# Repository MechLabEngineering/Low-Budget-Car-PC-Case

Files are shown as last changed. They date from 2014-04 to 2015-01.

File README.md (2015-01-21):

Low-Budget-Car-PC-Case
======================

Case for Tinkerforge IMU, GPS and MHS TinyCAN I-XL

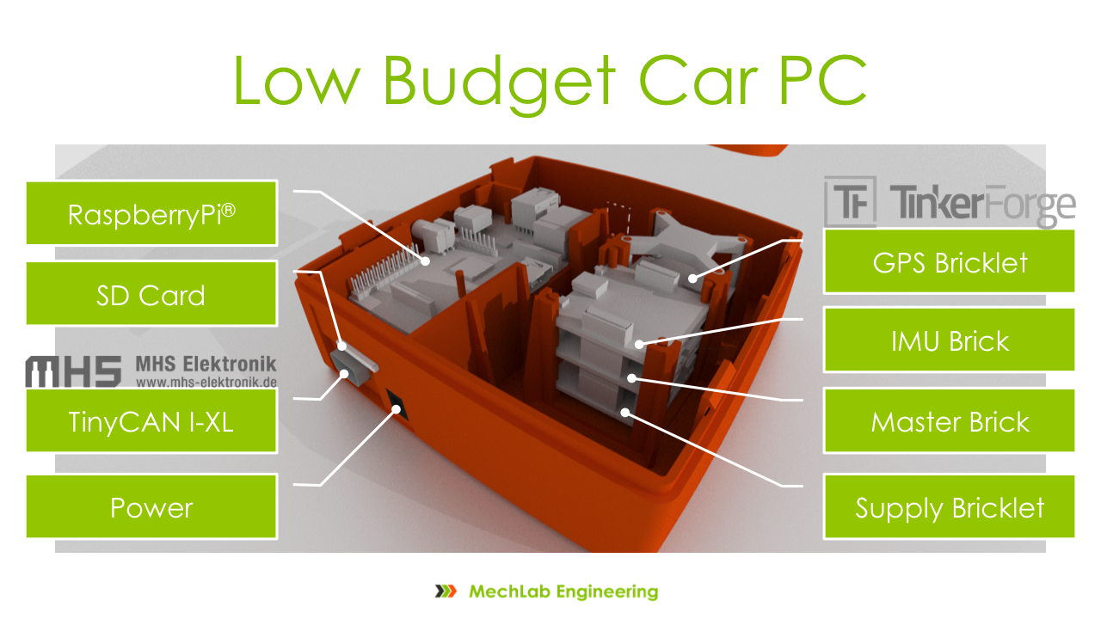
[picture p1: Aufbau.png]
Case


####http://mechlab-engineering.de/references/low-budget-car-pc/
####http://vimeo.com/mechlabengineering/lowbudgetcarpc

## Case for

* [RaspberryPi](http://www.watterott.com/de/Raspberry-Pi-Model-B)
* [Tinkerforge IMU Brick](http://www.tinkerforge.com/de/doc/Hardware/Bricks/IMU_Brick.html)
* [Tinkerforge GPS Bricklet](http://www.tinkerforge.com/en/doc/Hardware/Bricklets/GPS.html)
* [Tinkerforge Power Supply](http://www.tinkerforge.com/de/doc/Hardware/Power_Supplies/Step_Down.html)
* [MHS Elektronik TinyCAN I-XL](http://www.mhs-elektronik.de/index.php?module=content&action=show&page=tinycan_hardware)

With plugable

* USB UMTS Stick
* Ethernet Cable

## Status

We are currently in `Beta` state, that means we 3D printed it already and at least the hardware fits the case. We are tryin' to optimize the cables and the structure for cheaper 3D printing.

[Take a look here](http://mechlab-engineering.de/2014/04/erste-lieferung-car-pc-cases-eingeflogen/)

## Licence

[CC-BY-SA2.0](http://creativecommons.org/licenses/by-sa/2.0/de/) Raphael Borkert

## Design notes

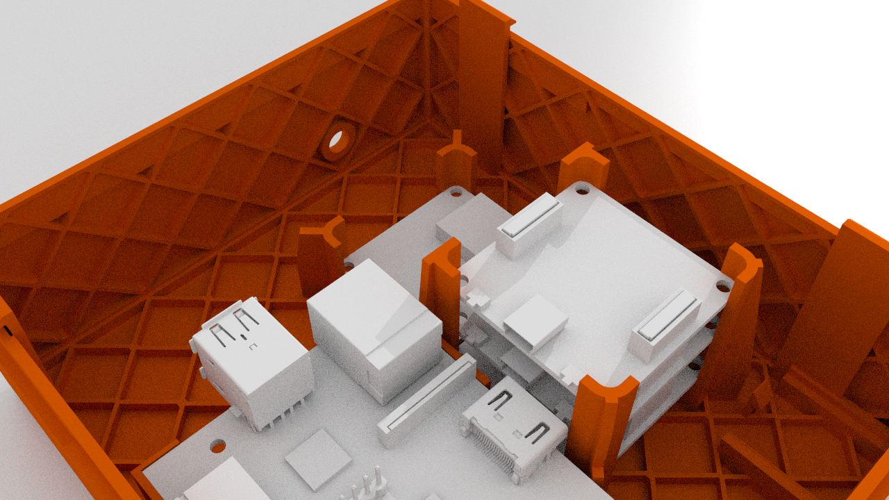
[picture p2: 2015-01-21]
Renderings/RenderingV3.png

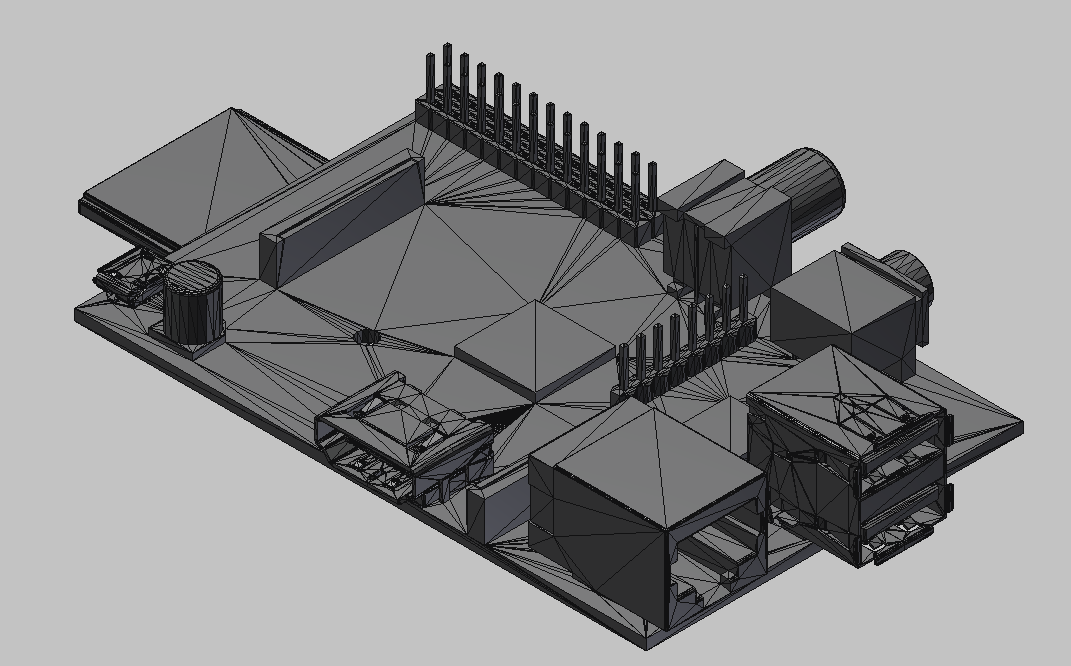
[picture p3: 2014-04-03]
STL-Dateien/RPi_STL_Low.PNG

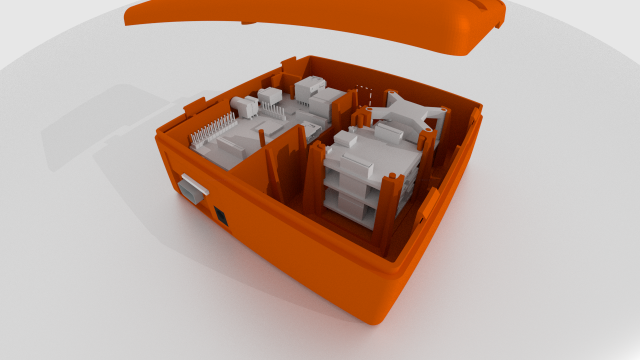
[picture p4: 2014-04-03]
Renderings/Rendering002.png

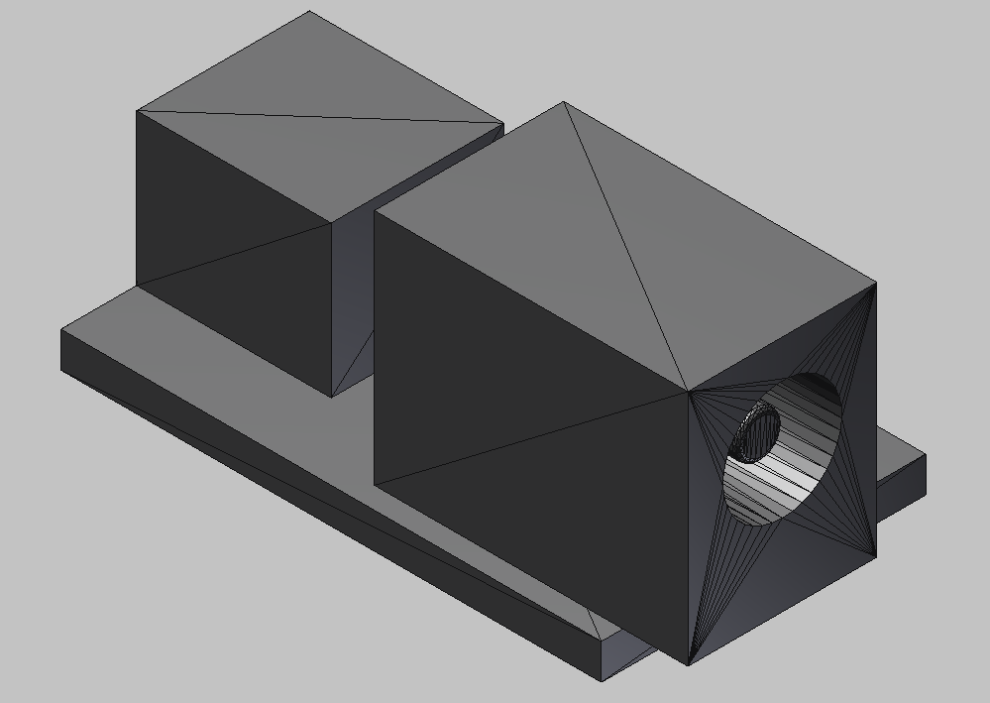
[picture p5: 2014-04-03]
STL-Dateien/DC_Jack_STL_Low.PNG

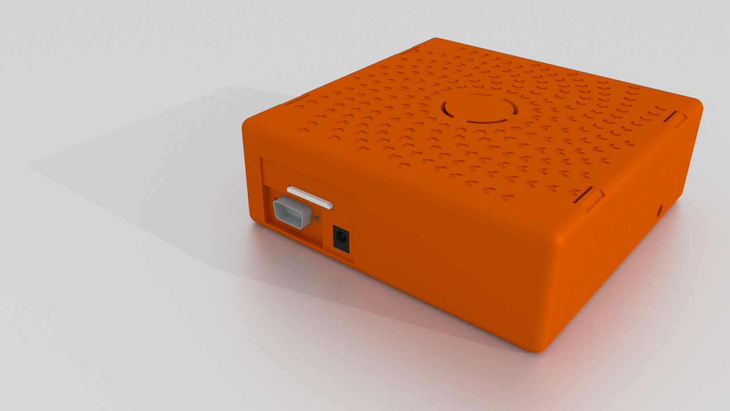
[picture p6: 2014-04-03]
Renderings/Rendering001.png

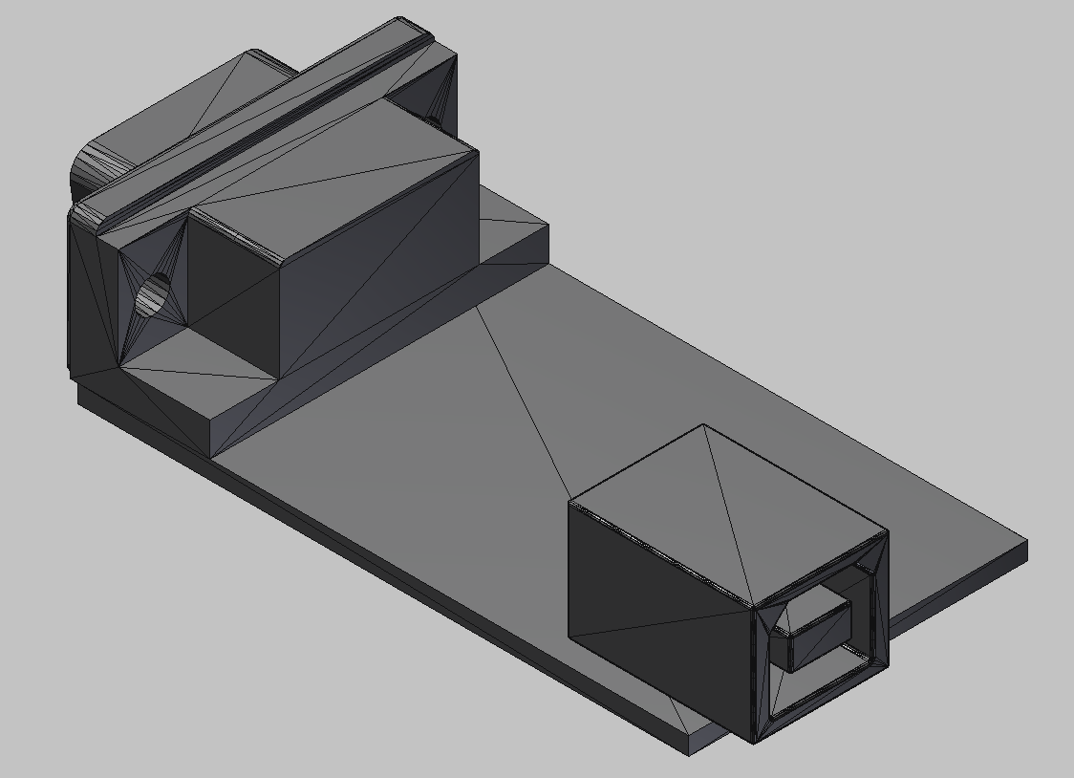
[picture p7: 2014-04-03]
STL-Dateien/Tiny_CAN_STL_Low.PNG

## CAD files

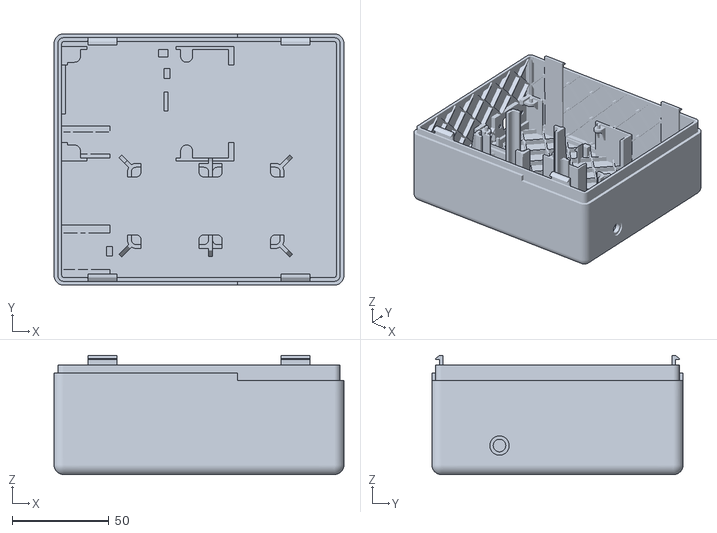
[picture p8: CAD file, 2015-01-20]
STL-Dateien/CarPC_Case_USV.stl
150.0 x 130.0 x 61.6

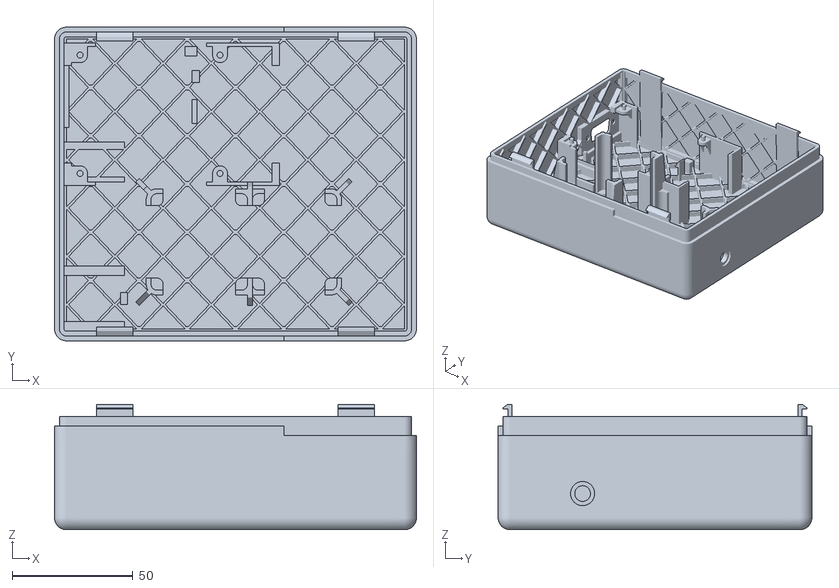
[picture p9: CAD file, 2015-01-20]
STL-Dateien/CarPC_Case.stl
150.0 x 130.0 x 52.0

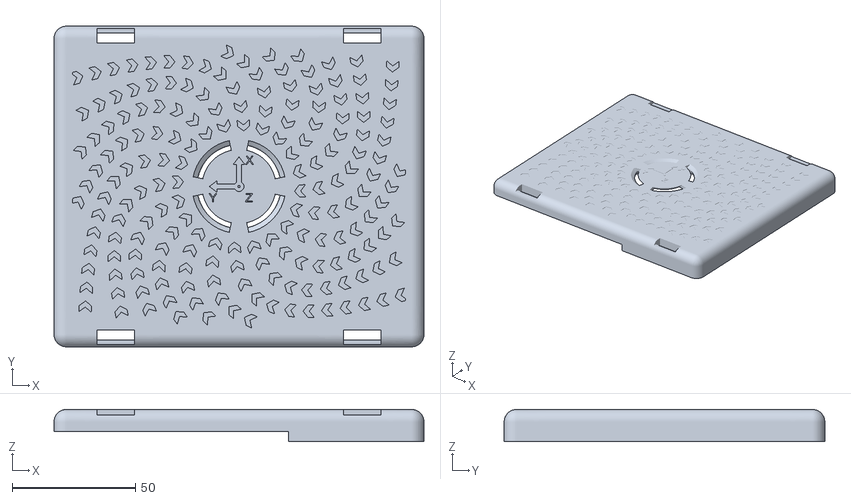
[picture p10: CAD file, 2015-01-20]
STL-Dateien/CarPC_Deckel.stl
150.0 x 130.0 x 13.0

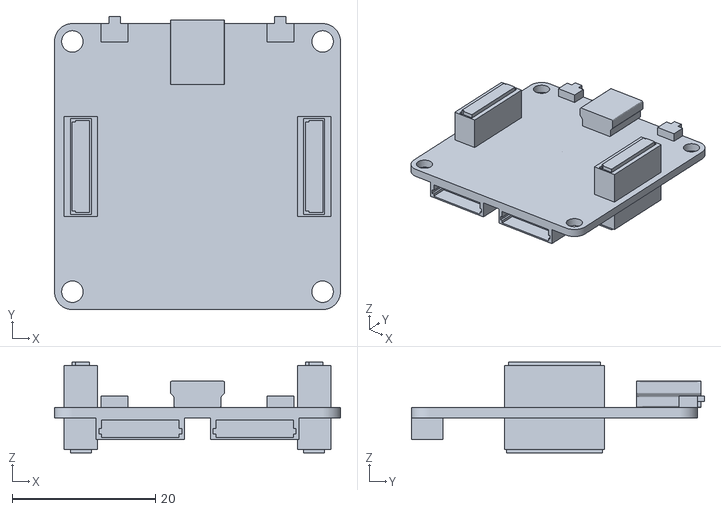
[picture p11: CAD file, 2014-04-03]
STL-Dateien/IMU.stl
40.0 x 41.0 x 12.7

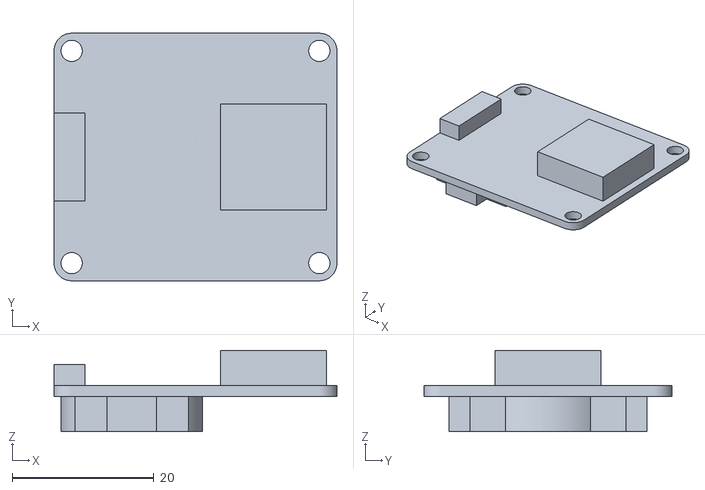
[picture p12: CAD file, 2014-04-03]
STL-Dateien/GPS_Bricklet.stl
40.0 x 35.0 x 11.5

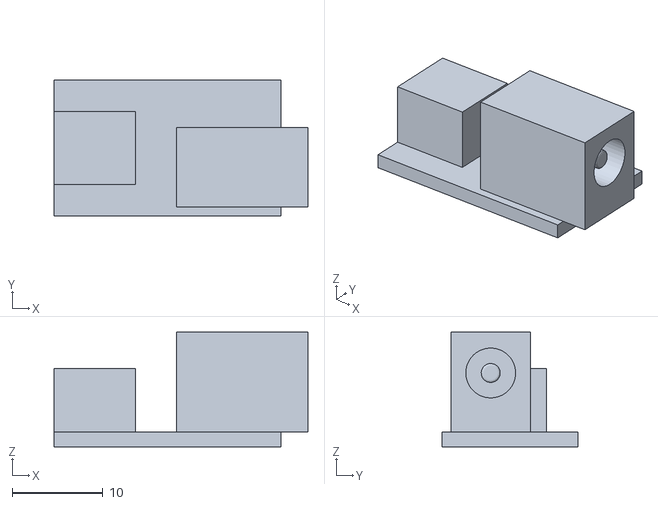
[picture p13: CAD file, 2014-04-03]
STL-Dateien/DC_Jack.stl
28.0 x 15.0 x 12.6

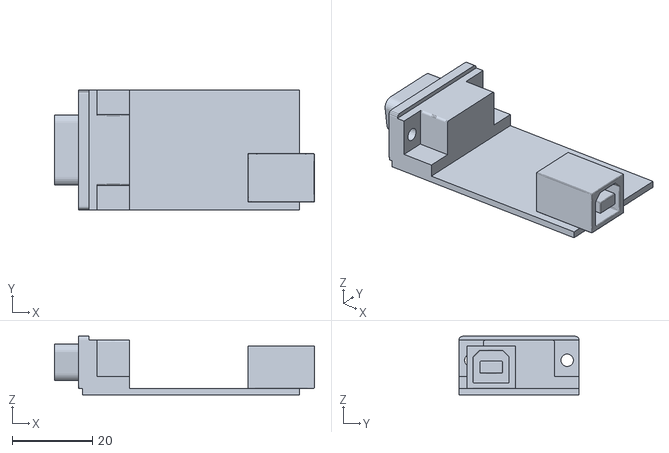
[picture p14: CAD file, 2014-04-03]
STL-Dateien/Tiny_CAN_I-XL.stl
64.8 x 30.0 x 14.6

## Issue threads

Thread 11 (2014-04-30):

Materialeinsparung

balzer82, 2014-04-30:
Mal checken, ob nicht noch ein bisschen Material eingespart werden kann (vielleicht Dicke vom Deckel oder Boden), um günstiger für 3D Druck zu werden.

RBorkert, 2015-01-20:
Es gibt nun zwei Versionen des Grundkörpers, V3.1 und V3.2. Sie unterscheiden sich nur in der Höhe der Box. Durch intensieve Umgestaltung und konsequenten Leichtbau konnte, im Vergleich zu Version V2, erheblich Material eingespart werden. Dies wirkt sich auch positiv auf die Kosten aus. V2 hatte einen Volumenbedarf von 211,71cm³. V3.1 benötigt 88,97cm³ (-58%), V3.2 99,52cm³ (-53%) Materialvolumen. Der Deckel passt bei beiden Versionen. Auch hier konnten weitere 17,5% Material gespart werden (56,62cm³ auf 46,7cm³). In der Mitte des Deckels ist jetzt die Orientierung der Achsen der IMU abgebieldet.

balzer82, 2015-02-10:
Die Seitenwände an denen der Deckel fixiert ist, könnten wieder etwas dicker werden (Wabenhöhe).

RBorkert, 2015-04-23:
Die Erhöhung der Steifigkeit der Seitenwände durch die Wabenhöhenvergrößerung ist im oberen Bereich der Seitenwände nicht Zielführend. Die maximale Höhe beläuft sich auf 1 bis 1,5 mm. Durch Stützleisten am Deckel wurde dennoch eine Erhöhung der Steifigkeit erreicht. Die Seitenwand stützt sich nun bei geschlossenem Deckel an diesem ab, ein extremes seitliches Eindrücken wird so unterbunden.

Closed 2015-04-23.

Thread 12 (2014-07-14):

RasPi B+ Anpassungen

balzer82, 2014-07-14:
Dieser Tage kommt der neue [RaspiB+](http://www.raspberrypi.org/blog/#introducing-raspberry-pi-model-b-plus) heraus, welcher leider völlig anders aussieht.

Zum Glück gibt es genaue geometrische Specs:
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

Außerdem:

* GPIO header has grown to 40 pins
* 4 USB 2.0 ports
* micro SD
* four squarely-placed mounting holes

RBorkert, 2015-01-20:
Der Grundträger für den Raspberry Pi B+ wurde angepasst. Anschlussmöglichkeiten für micro USB (DC), USB, GPIO und Ethernet wurden berücksichtigt. Es gibt zwei Größenausführungen der Box.

Closed 2015-01-20.

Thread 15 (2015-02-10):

Raspi Fixierung

balzer82, 2015-02-10:
Die Einpassung für den Raspi (samt Dorne für die Bohrungen) müsste etwas höher werden, damit der Raspi bei Erschütterung nicht locker wird.

RBorkert, 2015-04-23:
Die Halterung für den Pi wurde noch einmal überarbeitet. Sie hat jetzt einen kleinen Einschub, wo der Pi reinkommt. Auf der anderen Seite wird der durch zwei Pins und einen Chlip gehalten.

Closed 2015-04-23.

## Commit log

2014-04-04 Fix Wall Thickness
    [GRPi-01-000-000-2.stl]
2015-01-20 Delete GRPi-00-002-002.stl
    wird nicht mehr benötigt
    [GRPi-00-002-002.stl]
2015-01-20 Git Cleanup
    [CarPC_Case.stl, CarPC_Case_USV.stl, CarPC_Deckel.stl]
